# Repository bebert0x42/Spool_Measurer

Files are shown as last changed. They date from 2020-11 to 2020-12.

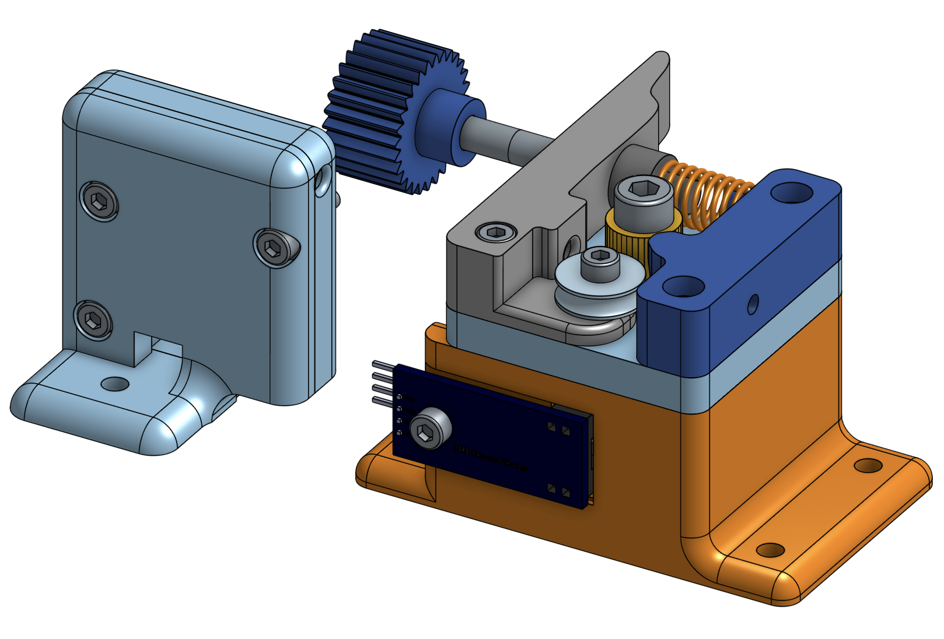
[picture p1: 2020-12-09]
Screenshot/Measurer 1.png

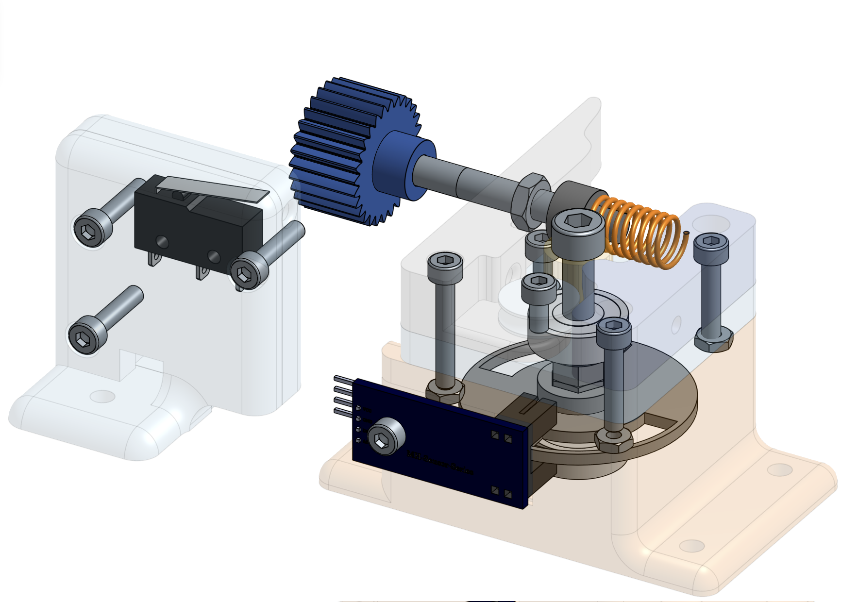
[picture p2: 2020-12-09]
Screenshot/Measurer 2.png

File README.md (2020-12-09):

# Spool_Measurer
Projet PIC IMT11

Spool Measurer 
Outil pour mesurer la quantité de filament d'une bobine et/ou de ré-embobiner une longueur de filament souhaitée.

OnShape     : https://cad.onshape.com/documents/6e38f85efcf624cf0dfd1f8a

Thingivers  : https://www.thingiverse.com/thing:4678732

Github      : https://github.com/bebert0x42/Spool_Measurer

Youtube     : https://youtu.be/fpB3lKIpQJo

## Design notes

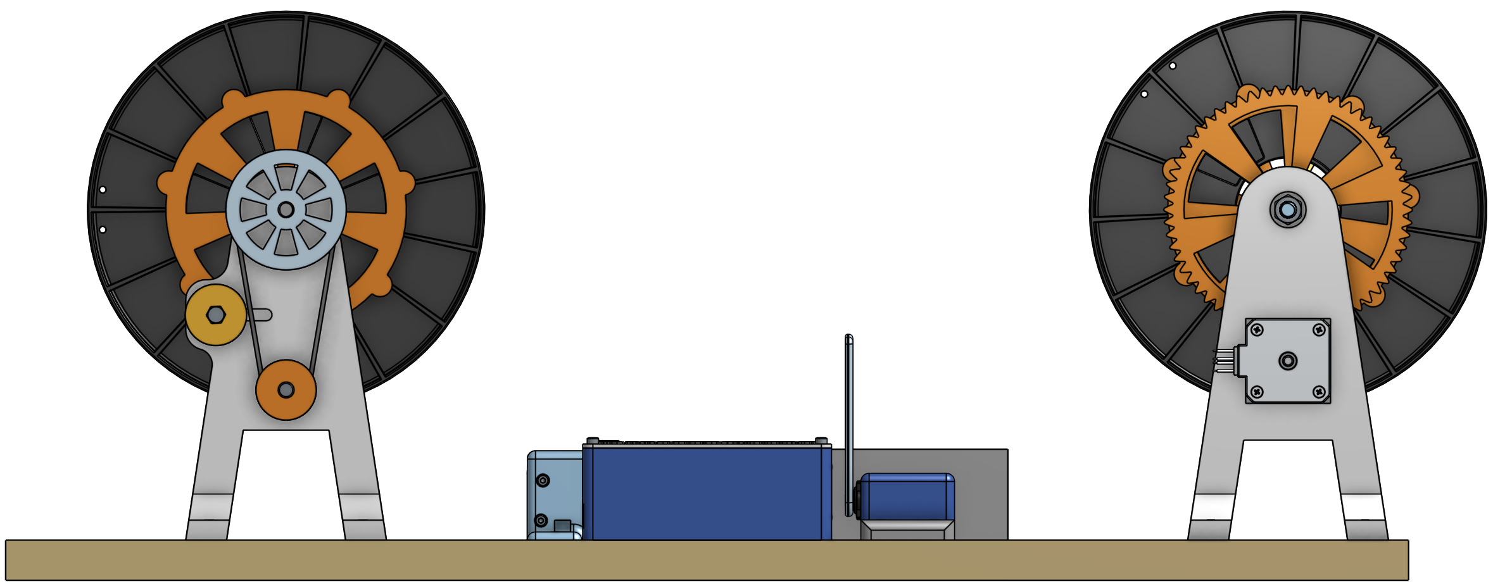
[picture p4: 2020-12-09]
Screenshot/Main 5.png

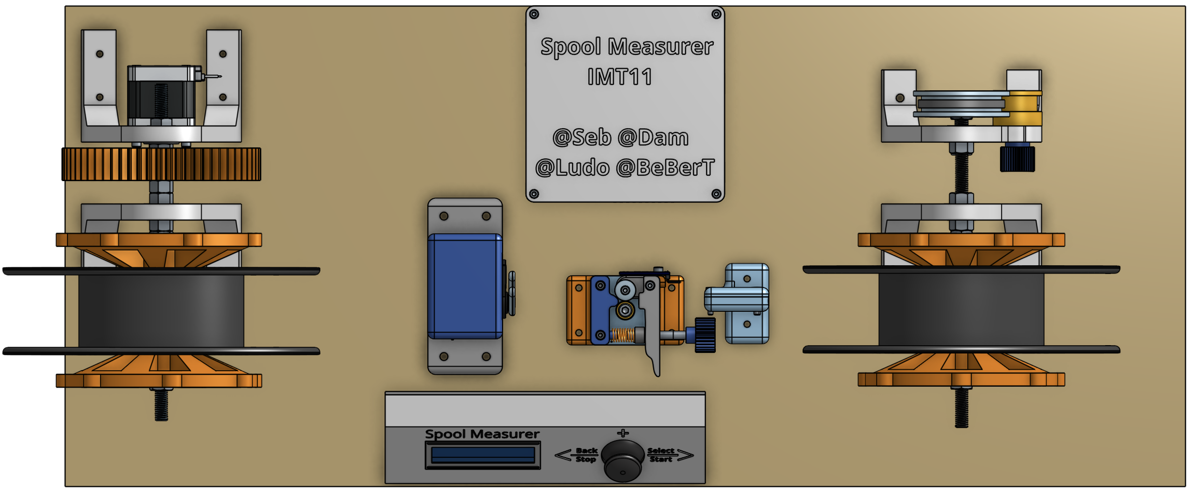
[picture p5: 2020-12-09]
Screenshot/Main 3.png

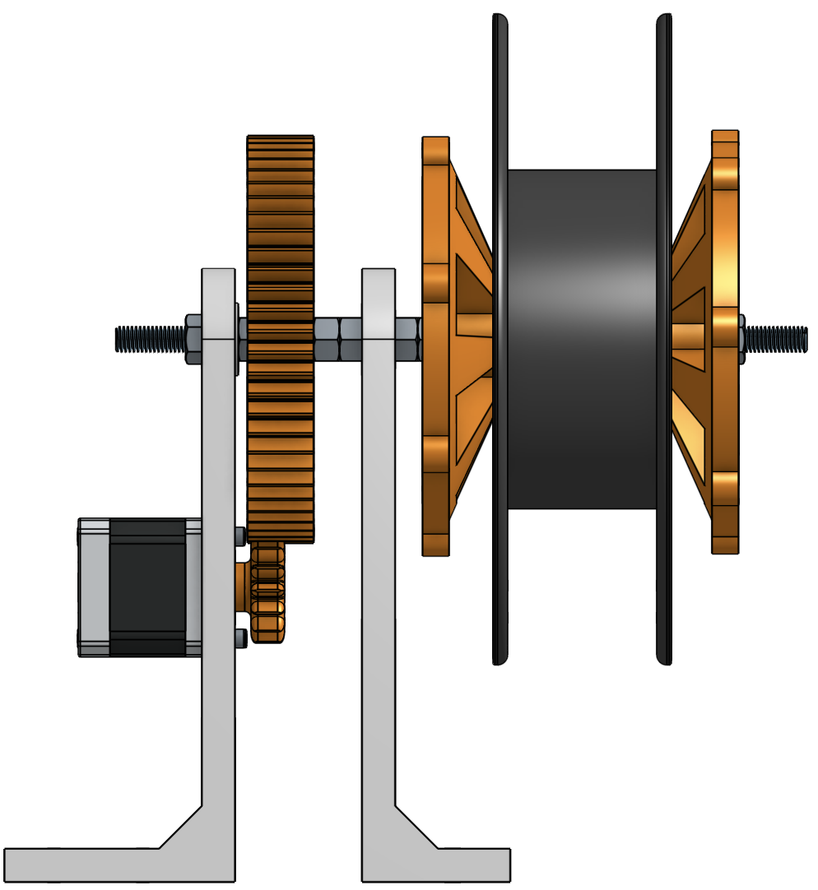
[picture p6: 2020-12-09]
Screenshot/Bobine Out 1.png

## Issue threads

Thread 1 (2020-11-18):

Mesure non fiable

bebert0x42, 2020-11-18:
https://github.com/bebert0x42/Spool_Measurer/blob/5927e75140fb0398a3032cdf96b8acb4e79dfd7f/beta_test.ino#L5-L5

bebert0x42, 2020-11-18:
Fix apres mise à jours de la fonction de mesure (tempo de 500 Microseconde + nouvelle vérification)

Closed 2020-11-18.

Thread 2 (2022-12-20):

erreur a la vérification du .ino

TownCryer, 2022-12-20:
C:\Users\Cedrick\Documents\Arduino\Spool_Measurer\Spool_Measurer.ino:74:10: fatal error: TimerOne.h: No such file or directory
 #include <TimerOne.h>
          ^~~~~~~~~~~~
compilation terminated.

exit status 1

Compilation error: TimerOne.h: No such file or directory

bebert0x42, 2022-12-20:
Hello,

Je ferai une réponse plus complète demain et avec la solution mais de mon souvenir :
Le paquet TimerOne permet d'utiliser un 3 eme timer sur l'arduino. Cependant tout les arduino ne sont pas compatible et il faut être sûr d'avoir le paquet pour compiler.

Plus d'info demain.

bebert0x42, 2022-12-21:
Du coup c'est bien ça :
Vérifie que dans le logiciel Arduino tu as bien TimerOne dans tes library (Sketch>>Include Library).
Si tu ne l'as pas, tu peux ajouter cette library dans Manage Librarie (Sketch>>Include Library).
Pour t'aider du à cette vidéo : https://youtu.be/igdBT0hwsJc?t=401

Closed 2022-12-21.

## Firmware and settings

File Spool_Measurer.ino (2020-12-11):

/*
  SpoolMeasurer.ino - Program for check size of spool - Version 1.0
  Copyright (c) 2020 Bertrand BOUVIER.  All right reserved.

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
  You should have received a copy of the GNU Lesser General Public
  License along with this library; if not, write to the Free Software
  Foundation, Inc., 51 Franklin St, Fifth Floor, Boston, MA  02110-1301  USA
*/

/* Release Candidate code pour projet PIC IMT11 SpoolMeasurer 						*/
/* Code : @BeBerT 																	*/
/* En charge du projet : @SebTr @DamCr @LudoGi @BeBerT 								*/
/* Library externe utilisé :  ServoTime2 : https://github.com/nabontra/ServoTimer2 	*/

/*

Liste des Bug :
- 

A faire :
- Ajout : Acceleration de la vitesse de setting de la longueure si appuye long sur X + et - ?


Fait/traité :
- Bug : Sur Auto_Init la modification de la valeure cible ne fonctionne pas bien (a cause des variables commande_push et commande_waiting)
- Add : Ajout d'un fine tunning lors du choix de la valeurs de la target a mesurer
- Add : Ajout d'une fonction reset target dans Window_Auto_init en clickan sur le joystick
- Bug : Sur Autu_run le joystick gauche vas sur Finished et non sur pause idem pour le droit.
- Bug : Sur l'ecran Manual Run, si on met la vitesse à 0 on ne peut plus la remonté directement sans passer par un autre menu
- Bug : Reset du compteur Timout APRES la mise en pause en auto et manu
- Bug : Sur tout les ecrans + et moins sont a désactivé sauf les ecrans de run
- Add : Ajout des execptions timeout
- Bug : Une fois la target atteint le programme continue (sur la fenetre Auto_Run)
- Bug : Si la vitesse de rotation est à 0 le timeout déclenche quand même
- Add : Passage en 1/8 de steps pour limiter le bruit moteur (configurable)
- Test : Test a 24V, le couple est un peu meilleur mais pas un gain important
- Test : L'alimentation 12V 2A suiffit (max 12V 1.2A utilisé)
- Add : Modification de la rampe de vitesse et dimminution de la vitesse max
- Bug : Lors de l'abort si la roue tourne le programme reprend (sur la fenetre Fail)
- Bug : le moteur n'est pas coupé lors de l'abort
- Bug : Affichage des RPM
- Add : définition complete des vitesses
- Add : Vérification de la limite d'améprage avec une alimentation plus forte 1.2 A max, 1A sur le driver
- Add : vérification en condition réel
- Add : Définition/calibration complete des distance_deceleration
- Bug : Apres une mesure, l'ancienne vitesse est en mémoire
- Add : Click sur le joystick sur les ecran window Manu reset le compteur
- BUG #1 Mesure non fiable, soit mettre un condensateur 100nf soit modifier le code pour une vérification de la lecture
		Update de la fonction measurement
- Ajout : Réduire taille des tiges fileté
- Ajout : Finir les fixations
- Ajout : Intégration du Servo moteur
- Ajout : Reduire le frame rate du LCD à 200ms (avec millis())
- Bug : X moins ne fonctionne plus --> Ajustement de la valeur XMoins
- Bug : quand on fait trop vite back back back le moteur ne se coupe pas
- Ajout : Calibration plus précise de la roues ? (Sur 10 m de filament mesuré, variation de 1cm en moyenne)
- Bug : Réduire la vitesse du servo moteur --> Ajout d'une constante de vitesse
- Ajout : Activer le servo QUE pendant la rotation
- Bug : Changer le design du support du servo pour contraindre le filament
- Ajout : Création boitier electrique
- Ajout : Imprimer Support IHM, ElectronicBox, métronome
- Bug : Augmenter l'angle du Guide : ok
- Ajout : Detecteur de fin de filament
- Bug : Ecran blink lors du faillure systeme
- Bug : Faire un balais de préinage pour la bobine In
- Bug : Happy stop vue une fois ?
- Bug : de la mesure et de la présence de filament --> Update du schémaeletrique (avec un NE555) plus passage des interrupts de Rising a falling
*/

#include <TimerOne.h>
#include <LiquidCrystal_I2C.h>
#include <ServoTimer2.h>


//******* Déclaration des Pin de l'arduino **********

	// PIN pour le Driver/Moteur A4988
	#define PIN_STEP 9
	#define PIN_DIR 8
	#define PIN_ENABLE_DRIVER 10

	LiquidCrystal_I2C lcd(0x27, 16, 2); // définit le type d'écran lcd avec connexion I2C sur les PIN SLA SCL

	//Pin du Joystick
	const int PIN_X = A0;	 // analog pin connected to X output
	const int PIN_Y = A1;	 // analog pin connected to Y output
	const int PIN_CLICK = 5; // Digital pin connected to Y output
	//Pin Fourche Optique
	const byte PIN_FOURCHE = 2; //Digital Pin connected to optical switch for interupt
	//const int PIN_A_FOURCHE = A3; //Analog pin to optical switch

	const int PIN_SERVO = 7;	// PWM Pin pour le servo moteur
	//Pin Switch fin de filament
	const int PIN_SWITCH = 3; //Analog Pin connected to Switch

//******* Déclaration des Variables de statu *************
	//Variable des bouton joystick
	bool X_PLUS = 0;
	bool X_MOIN = 0;
	//Origine centrale de la commande joystick X
	int XValue_origine;				  // Read the analog value from The X-axis from the joystick
	//Origine centrale de la commande joystick Y
	int YValue_origine;	
	bool Y_PLUS = 0;
	bool Y_MOIN = 0;
	bool CLICK = 0;
	// Variable pour attendre que le joystick se remete en 0
	bool commande_waiting = 1;
	// Variable pour push une commande joystick
	bool commande_push = 0;
	//Frame Rate de la mise a jours de commande en X
	unsigned int joystick_Tempo = 200;
	//Variable de temps en millis pour la tempo de la commande en X
	unsigned long joystick_Time = 0;
	int debug_var = 0; // variable de debugage

//****** Variable de statu ******

	// Démare/arrete le moteur a une vitesse donnée
	bool MOTOR_RUN = 0;
	// Active/Désactive le moteur et son couple
	bool MOTOR_ENABLE = 0;

//****** Variable de de fenetre IHM******

	//********| Spool Measurer |*********//
	//********|<-Manual  Auto->|*********//
	bool window_Menu = 1;
	//********|M.   Lgt:  1.93m|*********//
	//********|  Speed:0   rpm |*********//
	bool window_Manual_run = 0;
	//********|M.   Lgt:  1.93m|*********//
	//********|<-Menu   Start->|*********//
	bool window_Manual_init = 0;
	//********|     Paused     |*********//
	//********|     23.01 m    |*********//
	bool window_Manu_paused = 0;
	//********| Choose length! |*********//
	//********| Lgt:  23.01 m  |*********//
	bool window_Auto_init = 0;
	//********| 002.22m/230.00m|*********//
	//********|  Speed:0   rpm |*********//
	bool window_Auto_run = 0;
	//********|     Paused     |*********//
	//********|     23.01 m    |*********//
	bool window_Auto_paused = 0;
	//********|   Finished !   |*********//
	//********|     23.01 m    |*********//
	bool window_Finish = 0;
	//********| System Failure |*********//
	//********|<-Abort  Retry->|*********//
	bool window_Fail = 0;
	//********|   No Filament  |*********//
	//********|<-Abort  Retry->|*********//
	bool window_Fail_Presence = 0;

	//Frame Rate de la mise a jours de l'affichage en millis
	unsigned int window_Tempo = 0;
	//Variable de temps en millis pour la tempo de l'affichage
	unsigned long window_Time = 0;

//******* Variable pour le fonctinnement moteur **********
	int actual_speed = 1;
	int actual_direction;
	int target_speed;
	int ticks;
	int tick_count;
	// Constante de direction du moteur
	#define FORWARD HIGH
	#define BACKWARD LOW

//*********** Parametre de vitesse du moteur ***************

	const int speed_ticks[] = {-1, 600, 575, 550, 525, 500, 475, 450, 425, 400, 375, 350, 325, 300, 275, 240, 200, 170, 135, 120, 110, 95, 85, 75};
	size_t max_speed = (sizeof(speed_ticks) / sizeof(speed_ticks[0])) - 1; // nombre de variable dans le tableau
	const int microsteps = 8;											   // 1 Full step, 2 Half, 4 1/4 de step, 8 1/8 de steps

//******* Variable pour la fonction de mesure **********

	//Compteur du nombre de steps de la roue codeuse
	unsigned int counter_steps = 0;
	//Mesure de la longueure filament à l'instant T (afficher sur l'IHM)
	float measurement = 0;
	//La mesure ciblé de longueure de filament
	float measurement_target = 0;

	//                           IIIII
	//                           IIIII
	//     Variable pour         IIIII
	//      la calibration     IIIIIIIII
	//                          IIIIIII
	//                           IIII
	//                            II

	//périmetre de la roue denté de mesure en mm
	const float perimeter_gear = 0.03412;//0.03424;//0.03436;
	// avec une roue de 0.0339,   6m mesurer = 5.92m

	//nombre de fenetre sur la roue codeuse
	const int encoder_hole = 2;
	//Course de la bobine lors de la décélération de 60 RPM à 0
	const float distance_deceleration = 0.7;
	//Variable de temporisation pour éviter les faux signaux de la fourche optique
	static volatile unsigned long debounce = 0 ;
		//Variable de temporisation pour éviter les faux signaux ddu swhitch
	static volatile unsigned long debounce_switch = 0;
	//Temps de latence de la fourche optique pour s'assurer d'une bonne mesure
	const int latence_fourche = 500;
	bool counter_temp = false;

//******* Variable pour la fonction de TimeOut **********

	//Variable du dernier temps de mesure via millis()
	unsigned long previous_time_measurement = 0;
	//Temps en millisecond avant timeout (0.500s)
	const unsigned long timeout = 1000;
	//Variable du dernier temps de mesure via millis() + Timeout
	unsigned long check_time_measurement = 0;

//******* Variable pour la fonction guide du servo moteur **********

	ServoTimer2 servo_guide; //Servo name is myservo

	// Position du millieu du servo moteur en degres pendant le fonctionnement
	const int position_middle = 1400;
	// Course du servo moteur en microseconde pendant le fonctionnement
	const int position_variation = 800;
	// vitesse du guide en fonction de la vitesse du moteur
	const int position_speed = 10;
	// Position de départ du servo moteur en microseconde  pendant le fonctionnement
	const int position_start = position_middle - position_variation / 2;
	// Position de fin du servo moteur en microseconde pendant le fonctionnement
	const int position_end = position_middle + position_variation / 2;
	// Position actuel du servo moteur en microseconde (position de départ au démarage)
	int position_servo = 0;
	// Dernier temps en millis() que le servo moteur a bougé
	unsigned long position_tempo = 0;
	// Temps entre chaque mouvement d'une microseconde du servo moteur (en fonction de la vitesse du moteur)
	unsigned int position_running_time = speed_ticks[actual_speed];
	// Sens de direction du servo moteur
	bool direction_servo = 0;
	// Boolean de mémoire pour savoir si le servo doit recommencer à ça valeur présédente
	bool start_servo = 1;

/*
 * =============================================================================================
 * ========================================= Setup =============================================
 * =============================================================================================
*/
void setup()
{

	digitalWrite(PIN_ENABLE_DRIVER, HIGH); // Désactivation du moteur avant le setup

	// initial values
	actual_speed = 0;
	target_speed = max_speed / 2;
	actual_direction = BACKWARD;
	tick_count = 0;
	ticks = -1;

	// Init du Timer1, interrupt toute les 0.1ms pour lancer un step moteur
	Timer1.initialize(20);
	Timer1.attachInterrupt(timerMotor);


	//Initialisation du LCD I2C
	lcd.init();
	lcd.backlight();

	//Initialisation des PIN

	// pins DRIVER
	pinMode(PIN_ENABLE_DRIVER, OUTPUT);
	digitalWrite(PIN_ENABLE_DRIVER, HIGH); // Désactivation du moteur
	pinMode(PIN_STEP, OUTPUT);
	pinMode(PIN_DIR, OUTPUT);
	digitalWrite(PIN_DIR, actual_direction);

	// Pin Fourche
	pinMode(PIN_FOURCHE, INPUT);
	pinMode(PIN_CLICK, INPUT_PULLUP);
	pinMode(PIN_SWITCH, INPUT_PULLUP);

	// Init de l'interrupt de compteur de la fourche optique et de la présence en fonction du soulevement du signal
	attachInterrupt(digitalPinToInterrupt(PIN_FOURCHE), measure_filament, FALLING);
	attachInterrupt(digitalPinToInterrupt(PIN_SWITCH), presence_filament, FALLING);

	//init du servo Moteur Guide
	servo_guide.attach(PIN_SERVO); // attaches the servo signal pin
	delay(200);
	servo_guide.write(position_middle);// positionnement au milieu
	delay(400);
	position_servo = servo_guide.read(); // récupération de la position du servo moteur
	servo_guide.detach(); // désactivation du couple

	XValue_origine = analogRead(PIN_X);				  // Read the analog value from The X-axis from the joystick
	YValue_origine = analogRead(PIN_Y);	
}
/*
 * =============================================================================================
 * ======================================== Main Loop ==========================================
 * =============================================================================================
*/
void loop()
{
	//debug_var = digitalRead(PIN_SWITCH)+1;
	measurement = counter_steps * perimeter_gear / encoder_hole;

	read_joystick();   					// Lectue Joystick
	running_program(); 					// Boucle programme principal
	updateLCD();	   					// Mise a jours du LCD
	check_Target();						// Vérification si la mesure est proche de la cible
	servoGuide_Running();				// Rotation du Servo moteur Guide
	

	if (MOTOR_ENABLE && !window_Fail && !window_Fail_Presence) 	// Activation du moteur
	{
		digitalWrite(PIN_ENABLE_DRIVER, LOW);
	}
	else 								// Désactivation du moteur
	{
		digitalWrite(PIN_ENABLE_DRIVER, HIGH);
	}

	if (MOTOR_RUN && !window_Fail && !window_Fail_Presence) 		//Augmentation de la vitesse à la target
	{
		increase_speed();
	}
	else 								//Diminution de la vitesse du moteur jusqu'à l'arret
	{
		decrease_speed();
	}

	
	//Vérification que nous ne somme pas en TimeOut (plus de mesure depuis X secondes)
	check_time_measurement = previous_time_measurement + timeout;
	if (actual_speed > 0 && check_time_measurement < millis())
	{
		if (window_Auto_run || window_Manual_run)
		{
			window_Fail = 1;
			emergency_stop();
		}
	}
	else if (actual_speed <= 0 && check_time_measurement < millis())
	{
		previous_time_measurement = millis();
	}

	if (window_Menu)//pour corriger le bug
	{
		MOTOR_RUN = 0;
		MOTOR_ENABLE = 0;
	}
}

/********************************* Programme principal ****************************************
 * 
 *  - fonctionement du programme suivant la séquence IHM (voir fichier)
 * 
************************************************************************************************/
void running_program()
{
	if (!commande_push || !commande_waiting)
	{			// exclusion de windows fail ?
		return; //<- A tester VS le fonctionnement du programme en auto
	}

	if (window_Fail || window_Fail_Presence)
	{
		if (Y_MOIN)
		{ //abort du process et retour au menu principal
			resetIHM();
			MOTOR_RUN = 0;
			MOTOR_ENABLE = 0;
			window_Finish = 1;
		}
		if (Y_PLUS)
		{ //Retry avec reset du compteur timeout
			
			if (!digitalRead(PIN_SWITCH))
			{
				window_Fail_Presence = 1;
				window_Fail = 0;
			}
			else if ((window_Auto_run || window_Auto_paused || window_Auto_init) )
			{
				MOTOR_RUN = 1;
				window_Fail = 0;
				window_Fail_Presence = 0;
				previous_time_measurement = millis();
			}
			else if ((window_Manu_paused || window_Manual_init || window_Manual_run) )
			{
				MOTOR_RUN = 1;
				window_Fail = 0;
				window_Fail_Presence = 0;
				previous_time_measurement = millis();
			}
		}
	}
	else if (window_Menu)
	{
		counter_steps = 0;
		MOTOR_RUN = 0;
		if (Y_MOIN)
		{
			resetIHM();
			window_Manual_init = 1;
			target_speed = max_speed / 2;
		}
		else if (Y_PLUS)
		{
			resetIHM();
			window_Auto_init = 1;
			target_speed = max_speed / 2;
		}
	}
	else if (window_Manual_init)
	{
		if (Y_MOIN)
		{
			resetIHM();
			window_Menu = 1;
		}
		else if (Y_PLUS)
		{
			resetIHM();
			window_Manual_run = 1;

			if (!digitalRead(PIN_SWITCH))
			{
				window_Fail_Presence = 1;
			}
			else
			{
				MOTOR_RUN = 1;
				previous_time_measurement = millis();
			}

		}
	}
	else if (window_Manual_run)
	{
		if (Y_MOIN)
		{
			MOTOR_RUN = 0;
			resetIHM();
			window_Manu_paused = 1;
		}
		else if (Y_PLUS && actual_speed == 0)
		{
			MOTOR_RUN = 1;
			target_speed = max_speed / 2;

		}
	}
	else if (window_Manu_paused)
	{
		if (Y_MOIN)
		{
			resetIHM();
			window_Finish = 1;
		}
		if (Y_PLUS)
		{
			resetIHM();
			window_Manual_run = 1;
			if (!digitalRead(PIN_SWITCH))
			{
				window_Fail_Presence = 1;
			}
			else 
			{
				
				MOTOR_RUN = 1;
				previous_time_measurement = millis();
			}

		}
	}
	else if (window_Finish)
	{
		if (Y_MOIN || Y_PLUS)
		{
			resetIHM();
			window_Menu = 1;
			MOTOR_RUN = 0;
			MOTOR_ENABLE = 0;
		}
	}
	else if (window_Auto_init)
	{
		if (Y_MOIN)
		{
			resetIHM();
			window_Menu = 1;
		}
		else if (Y_PLUS && measurement_target > 0)
		{
			resetIHM();
			window_Auto_run = 1;
			if (!digitalRead(PIN_SWITCH))
			{
				window_Fail_Presence = 1;
			}
			else 
			{
				
				MOTOR_RUN = 1;
				previous_time_measurement = millis();
			}
		}
	}
	else if (window_Auto_run)
	{
		if (Y_MOIN)
		{
			MOTOR_RUN = 0;
			resetIHM();
			window_Auto_paused = 1;
		}
	}
	else if (window_Auto_paused)
	{
		if (Y_MOIN)
		{
			resetIHM();
			window_Finish = 1;
		}
		if (Y_PLUS)
		{
			window_Auto_run = 1;
			resetIHM();
			if (!digitalRead(PIN_SWITCH))
			{
				window_Fail_Presence = 1;
			}
			else 
			{
				
				MOTOR_RUN = 1;
				
				previous_time_measurement = millis();
			}
		}
	}
	commande_waiting = 0;
}

/********************************* Fonction de check de la mesure VS Targe *********************
 * 
 * - Permet de vérifier si la valeur measurement est proche de la target pour diminuer la vitesse
 * du moteur
 * - Passe window_Finish à 1 si la target est ok et coupe le moteur
 * 
************************************************************************************************/
void check_Target()
{

	if (measurement_target > 0 && window_Auto_run)
	{
		/* Code pour le fonctionnement du moteur en fonction de la cible a mesurer*/
		if (measurement >= measurement_target)
		{
			MOTOR_RUN = 0;
			resetIHM();
			window_Finish = 1;
		}
		else if (measurement + distance_deceleration >= measurement_target)
		{
			target_speed = 1;
		}
	}
}

/********************************* Fonction Diminution de la vitesse Moteur *********************
 * 
 * - Augmentation de la vitesse moteur en fonction des valeurs du tableau speed_ticks
 * 
************************************************************************************************/
void increase_speed()
{

	if (actual_speed < target_speed)
	{
		actual_speed += 1;
		tick_count = 0;
		ticks = speed_ticks[actual_speed] / microsteps;
	}
	else if (actual_speed > target_speed)
	{
		actual_speed -= 1;
		tick_count = 0;
		ticks = speed_ticks[actual_speed] / microsteps;
	}
}

/********************************* Fonction Diminution de la vitesse Moteur *********************
 * 
 * - Diminution de la vitesse moteur en fonction des valeurs du tableau speed_ticks
 * 
************************************************************************************************/
void decrease_speed()
{

	if (actual_speed > 0)
	{
		actual_speed -= 1;
		tick_count = 0;
		ticks = speed_ticks[actual_speed] / microsteps;
	}
}

/********************************* Fonction arret d'urgence Moteur ******************************
 * 
 * - Non utilisé
 * 
************************************************************************************************/
void emergency_stop()
{
	actual_speed = 0;
	tick_count = 0;
	//ticks = speed_ticks[actual_speed / 5]/microsteps;
}

/********************************* Fonction TimerMotor *****************************************
 *
 * - Fonction lancé toute les 20ms avec au Timer1
 * - Fait tourner le moteur un tour en fonction de la vitesse
 * 
************************************************************************************************/
void timerMotor()
{


	if (actual_speed == 0)
		return;

	digitalWrite(PIN_ENABLE_DRIVER, LOW); // Activation du moteur
	MOTOR_ENABLE = 1;					  //Flag motor en marche

	tick_count++;

	if (tick_count == ticks)
	{
		// 1 step du moteur
		digitalWrite(PIN_STEP, HIGH);
		digitalWrite(PIN_STEP, LOW);

		tick_count = 0;
	}
}

/********************************* Fonction ServoGuide_Running *****************************************
 *
 * - Fonction pour mettre en mouvement le servo moteur du guide en fonction de la vitesse du moteur
 * - Fait tourner le servo moteur suivant les paramettres 
 * 
************************************************************************************************/
void servoGuide_Running()
{
	if (MOTOR_RUN && MOTOR_ENABLE)
	{
		servo_guide.attach(PIN_SERVO); // attaches the servo signal pin

		if (start_servo)
		{
			position_servo = servo_guide.read(); // récupération de la position du servo moteur
			start_servo = 0;
		}
		
		position_running_time = speed_ticks[actual_speed] * 2 ;

		if ((position_tempo + position_running_time) < millis())
		{
			position_tempo = millis();
			if (!direction_servo && position_servo < position_end)
			{
				position_servo = position_servo + position_speed;
			}
			else if (!direction_servo && position_servo >= position_end)
			{
				direction_servo = !direction_servo;
			}
			else if (direction_servo && position_servo > position_start)
			{
				position_servo = position_servo - position_speed;
			}
			else if (direction_servo && position_servo <= position_start)
			{
				direction_servo = !direction_servo;
			}
			
			servo_guide.write(position_servo);
			
			//debug_var = position_servo;
		}
	}
	else if (start_servo == 0)
	{
		servo_guide.detach(); // coupe le couple du servo moteur guide
		start_servo = 1;
	}
	
}
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
